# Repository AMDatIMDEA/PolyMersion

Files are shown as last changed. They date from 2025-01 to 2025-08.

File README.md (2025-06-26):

# PolyMersion

Automated Procedure for Polymer Degradation Testing through Water Immersion using UR10-e Robot Arm

---
### Project Structure

This repository contains two versions of the experimental workflow:

- `scripts_v1`: Single-bath experiment version.
- `scripts_v2`: Dual-bath experiment version.

Each version is self-contained and configurable via a `config.json` file and a separate README.md file for a more thorough explanation.

---

## Overview

This repository contains the final version of the CAD models, 3D printable STL files, and Python scripts used to automate and execute the experimental workflow for Polymer Degradation Testing using UR10-e Robot Arm. Also includes the code for the Arduino.

## Repository Structure

```
PolyMersion/ 
├── CAD/ 
├── STL/
├── data/
├── Arduino/
├── scripts_v1/
│ ├── README.md
│ ├── main.py 
│ ├── config.json
│ ├── robot.py
│ ├── gripper.py
│ ├── degradation.py
│ ├── environment.py 
│ └── data_processing.py
├── scripts_v2/
│ ├── README.md
│ ├── client.py
│ ├── listener.py
│ ├── config1.json
│ ├── config2.json
│ ├── robot.py
│ ├── gripper.py
│ ├── degradation.py
│ ├── environment.py 
│ └── data_processing.py
├── requirements.txt
└── README.md
```

## How to use
### 1. 3D Printing Components

- The STL files located in the `STL` folder are ready to be used for 3D printing.
- Print the files according to the material and printer specifications suitable for the experiment.
- Included are files for designing trays for impact and tensile test samples, and a README.md file specifying the tray assembly.

### 2. Wiring the circuit
- Follow the circuit depicted in `Arduino\Schematic.png` using the components listed in the publication describing the experiment or adapting them to your use case.
  
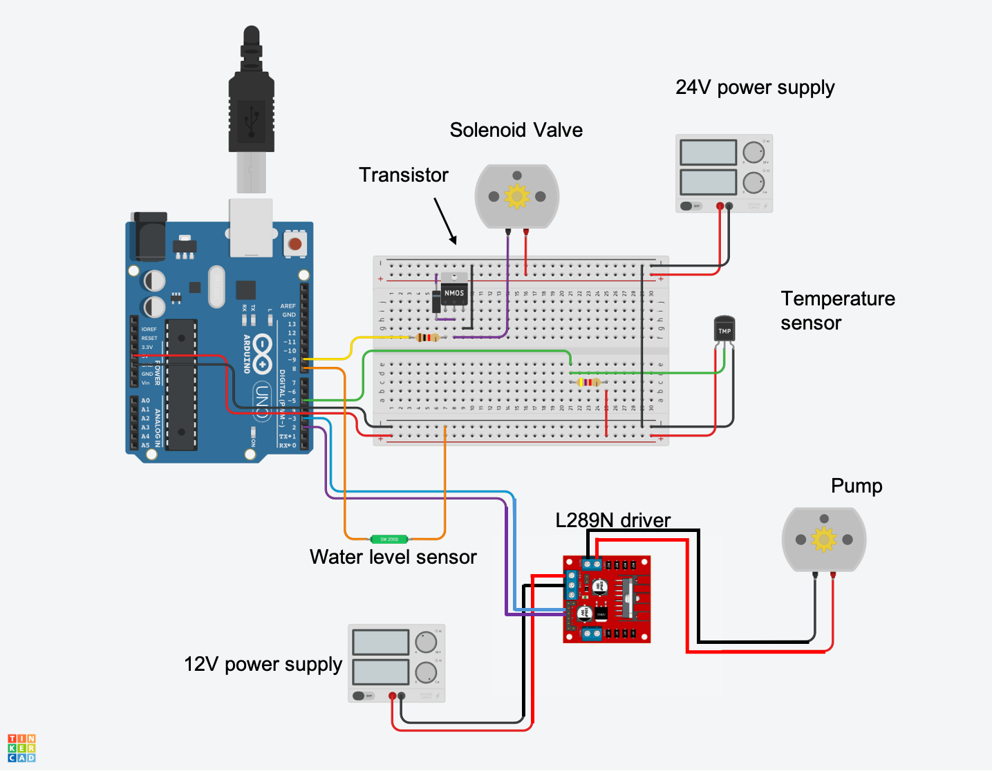
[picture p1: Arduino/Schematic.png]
Circuit schematic


### 3. Running the Workflow

- Parameters such as the number of specimens, cycle length, and other relevant variables can be adjusted by modifying the `config.json` file.
- No changes to the Python code are necessary—simply update the JSON file to reflect the desired settings.

1. Clone this repository:
```
git clone https://github.com/AMDatIMDEA/PolyMersion.git
```

2. Choose the version you want to use:
   - For single bath → `cd PolyMersion/scripts_v1`
   - For dual bath → `cd PolyMersion/scripts_v2`
     
3. Upload the Arduino code:
   ```bash
   cd PolyMersion/Arduino/PoliMersion
   open PoliMersion.ino  # Or use the Arduino IDE
   ```

3. Install the required Python packages:
   ```bash
   pip install -r requirements.txt
   ```

4. Edit the `config.json` file to configure your experiment (see below).

5. Run the workflow following the instructions in the README.md file that you have chosen.

### 4. Configuration

- The `config.json` file allows users to easily configure the experiment without altering the codebase.
- Example of a `config.json` structure:

```
{
    "robot": {
        "robot_ip": "192.168.9.29",
        "setup": 1,
        "choice": 1 # 1: Extract samples to external tray, 2: Leave the samples in the internal tray	
    },
    "experiment": {
        "material": "PLA",
        "temperature": 40,
        "cycles": 23,
        "subcycles": 1,
	"samples_per_subcycle": 10,
	"starting_cycle": 15
    },
    "grid": {
        "columns": 23,
        "rows": 11
    },
    "timing": {
        "hours_delay": 5,
        "minutes_delay": 0
    }
}
```
> 💡 Each version (`scripts_v1`, `scripts_v2`) may have slightly different config parameters depending on bath logic. Check the `config.json` in each folder for version-specific options.

---
## Requirements

- Python 3.x
- Required libraries listed in `requirements.txt`

## Compatibility  

This project has been tested on:

- ✅ macOS
- ✅ Linux
  
> ⚠️ If `python` or `pip` refers to Python 2 on your system, use `python3` and `pip3` instead.

## Notes
- Make sure the 3D printed components match the CAD models used in the experiment.
- If adjustments to the CAD models are required, source files can be found in the CAD folder.

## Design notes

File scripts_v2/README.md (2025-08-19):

# PolyMersion - Two-Bathroom Version (with queuing system)

This version runs the experiment with **two simultaneous baths**, managed through a queuing system. It uses sockets to coordinate the robot's movements in parallel.

---

## Architecture

- `listener.py`: Server that manages queued client requests.
- `client.py`: Client that represents a bath experiment.
- Communication based on TCP/IP sockets.
- Ideal for experiments with multiple groups in parallel.

---

## Execution

1. Navigate to the directory:
```bash
cd PolyMersion/scripts_v2
```

2. Upload the code to Arduino:
```bash
cd ../../Arduino/PoliMersion
open PoliMersion.ino
```

3. Install the dependencies:
```bash
pip install -r requirements.txt
```

4. Run the `listener` (server):
```bash
python listener.py
```

5. In another terminal, run one or more `client.py` scripts:
```bash
python client.py --config config1.json --setup 1
```

---

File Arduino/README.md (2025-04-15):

# Arduino code for PolyMersion experiments

This folder contains the Arduino code to run the Polymersion experiments with one or two water baths. 

The schematics for running with only one bath are presented in the following figure:

Circuit schematic

In case of using two water baths, you will need to install a new water level sensor, temperature sensor and add another pump to the free ports in the L289N driver. 

All Dallas Temperature sensors share the data transfer pin throught the One Wire protocol, and are differenciated by their address. This guide explains in detail the wiring and how to find the adress so it can be scaled to multiple water baths:
https://lastminuteengineers.com/multiple-ds18b20-arduino-tutorial/

To install the Arduino code in the board, use Arduino GUI or the Arduino CLI tool. The OneWire.h and DallasTemperature.h libraries are required.

The code serves three functions:
1. Refill each of the water baths when their corresponding floating switch detects that the water level is low.
2. Send the temperature sensors reading every time it receives a serial request (sent by the python code) to keep track of the temperature.
3. Open the compressed air valve to dry the specimens every time it's requested, again via serial.

The code is commented in detail so every function can be modified if needed to extend functionality or the number of water baths available.

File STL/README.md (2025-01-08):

# 3D Printing Guide for PolyMersion  

## Overview  
This folder contains the STL files required to fabricate the components for the Polymer Degradation Testing setup. The parts are designed to be printed using standard 3D printers and assembled for the UR10-e Robot Arm experiment.  

## Components to Print  

### Required Pieces:  
- **Base Plate (x1)** – The foundational structure for mounting the grid and supporting the specimens.  
- **Top Plate (x1)** – The upper structural part that holds specimens in place.  
- **Intermediate Trays (x2 or more)** – Adjustable trays that hold the polymer samples during testing.
- Remember that 2 trays are neccesary, one for the water bath and the other one outside.  

### Additional Components:  
- **Screw covers** - To maintain the structure.
- **Tray Connectors** – Connectors are included to join trays if they need to be printed in separate sections.  
- **Complements** – Complementary parts as water level controller, scale adapter and gripper. 

## Printing Instructions  
1. **Print Orientation and Size**:  
   - Ensure that large components are printed flat to minimize warping.
     
2. **Printing in Parts**:  
   - The **STL files** in this directory are pre-sliced into three parts for each layer of the tray to fit standard print beds, such as the Bambu printer.
   - CAD files are included to modify this pre-slicing.
   - Use the **tray connectors** to reassemble parts post-printing.  
   - The STL files for the connectors and joining pieces are provided in this folder.  

3. **Material Recommendation**:  
   - Use **ASA** for structural integrity and resistance to degradation under experimental conditions.  
   - Ensure all components are printed with a minimum of 3 perimeters and 30% infill for durability.  

4. **Post-Processing**:  
   - Light sanding may be required to ensure that connectors and assembled sections fit smoothly.  
   - Test-fit all components before final assembly.  

## Assembly Notes  
- Refer to the CAD models to visualize the complete assembly.  
- Ensure the top and base plates align correctly with the trays and connectors.  
- Tighten all clips and connectors to secure the experiment structure.
- If you encounter any issues during printing or assembly, consider scaling components slightly or adjusting slicing parameters. 

## Files Included  
- **STL Files** – Ready-to-print 3D models.  

---
**Note:**  
If adjustments to the design are required, the CAD folder contains the editable models. Modify them as needed to fit your experimental setup or printer specifications.

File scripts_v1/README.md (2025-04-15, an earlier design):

# PolyMersion - Single-Bath Version

This script allows you to automatically run a polymer sample immersion experiment using a single bath, a UR robot, and an Arduino.

---

## Execution

1. Navigate to the directory:
```bash
cd PolyMersion/scripts_v1
```

2. Configure the experiment by editing the `config.json` file.

3. Upload the code to Arduino:
```bash
cd ../../Arduino/PoliMersion
open PoliMersion.ino # Or open it with the Arduino IDE
```

4. Install the dependencies:
```bash
pip install -r requirements.txt
```

5. Run the experiment:
```bash
python main.py
```

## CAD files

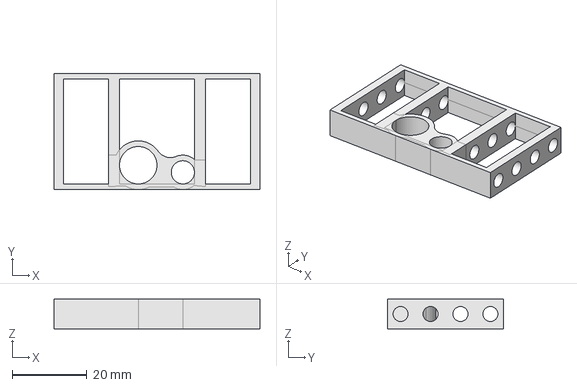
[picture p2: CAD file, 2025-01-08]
CAD/PolyMersion_center_platform.FCStd
55.0 x 31.0 x 8.00 mm

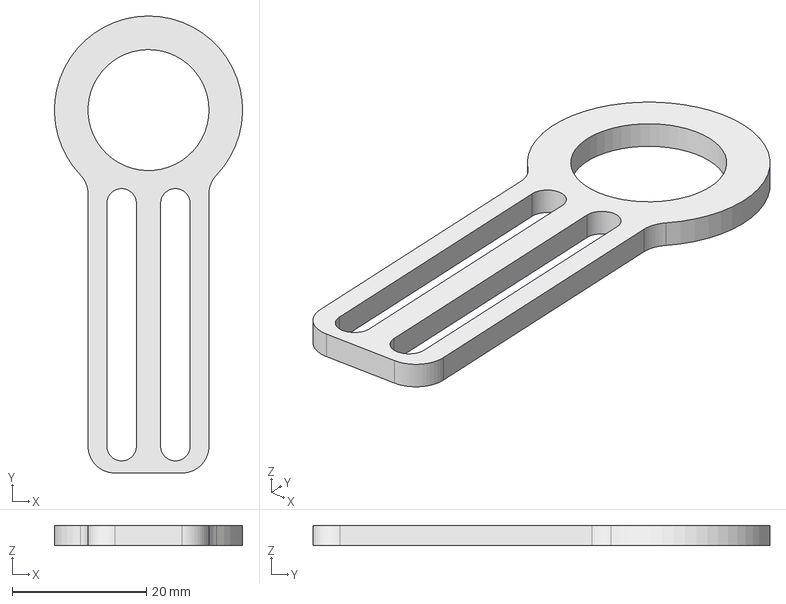
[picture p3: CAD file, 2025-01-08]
CAD/PolyMersion_water_level_control.FCStd
28.0 x 68.0 x 3.00 mm

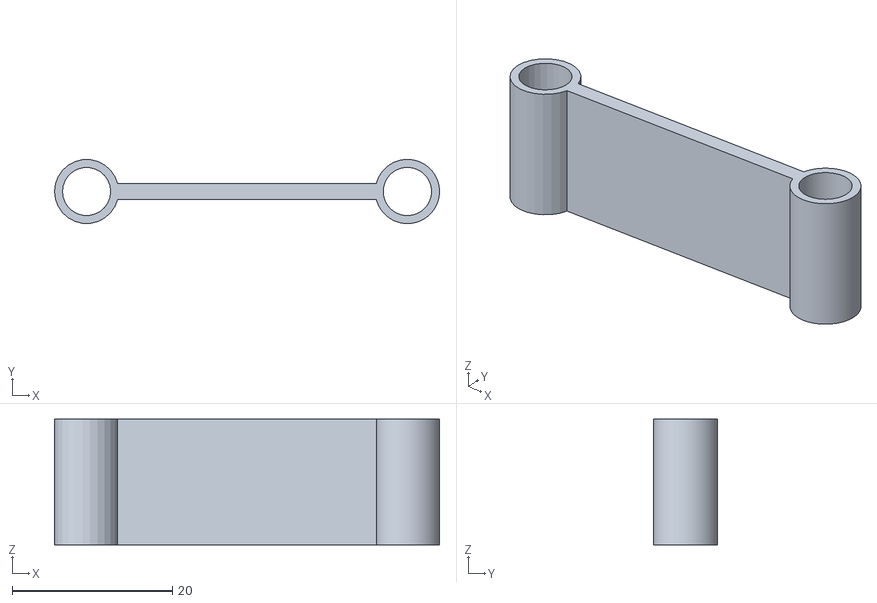
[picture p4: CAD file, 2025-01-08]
STL/PolyMersion_tray_joint.stl
48.0 x 8.00 x 15.7

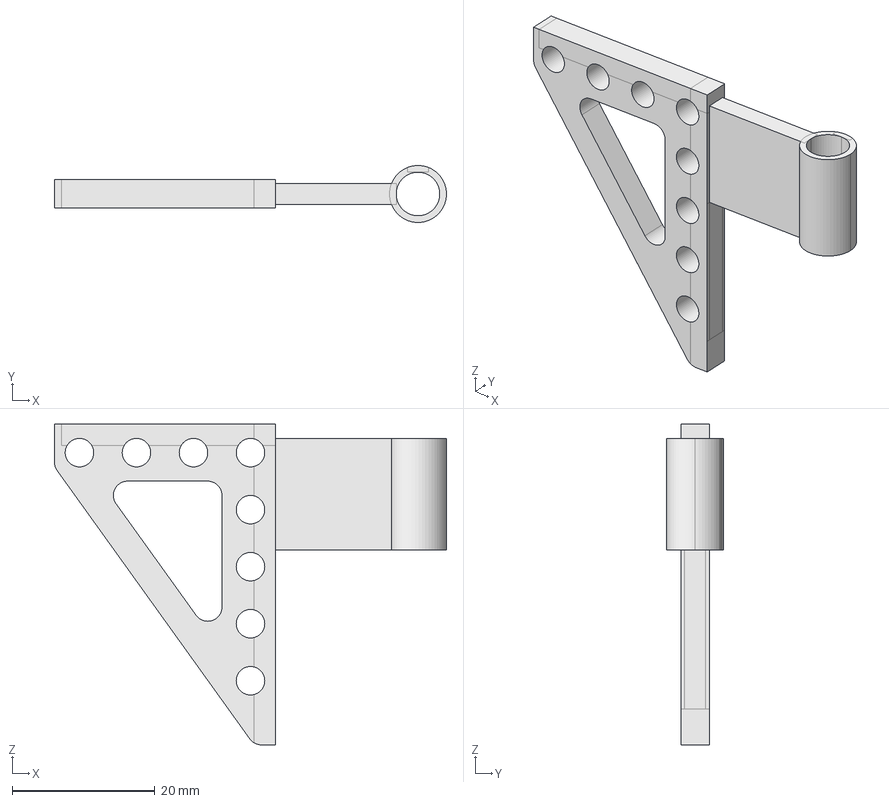
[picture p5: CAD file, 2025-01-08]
CAD/PolyMersion_center_tray_bracket.FCStd
55.0 x 7.99 x 45.0 mm

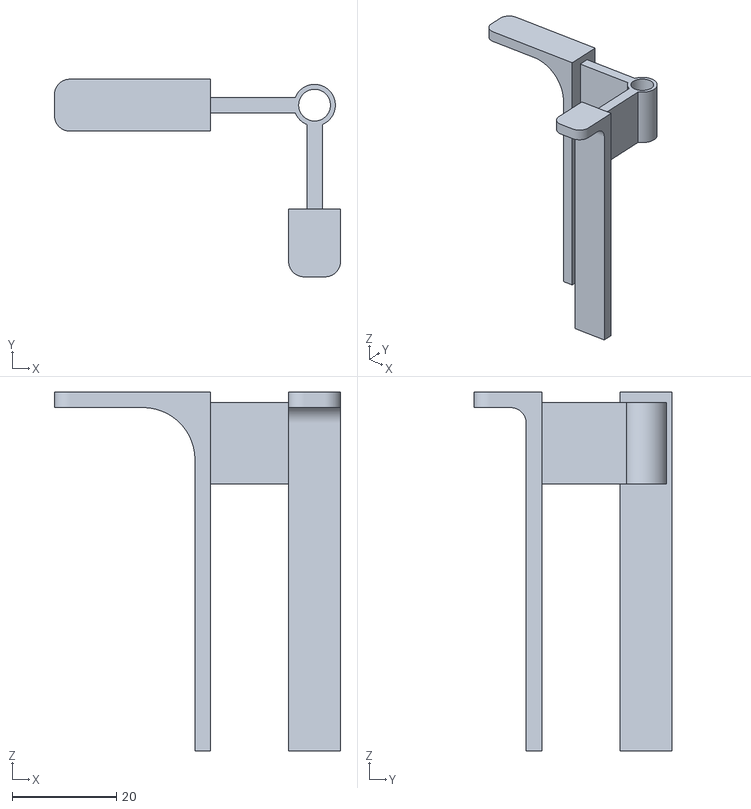
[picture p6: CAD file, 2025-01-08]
STL/PolyMersion_corner_R.stl
55.0 x 38.0 x 69.0

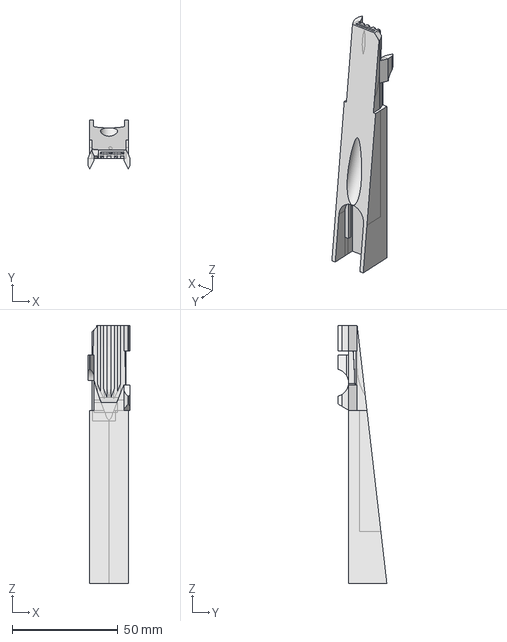
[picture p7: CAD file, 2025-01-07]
CAD/Polymersion_grip_air_8mm.FCStd
20.0 x 23.0 x 121.8 mm

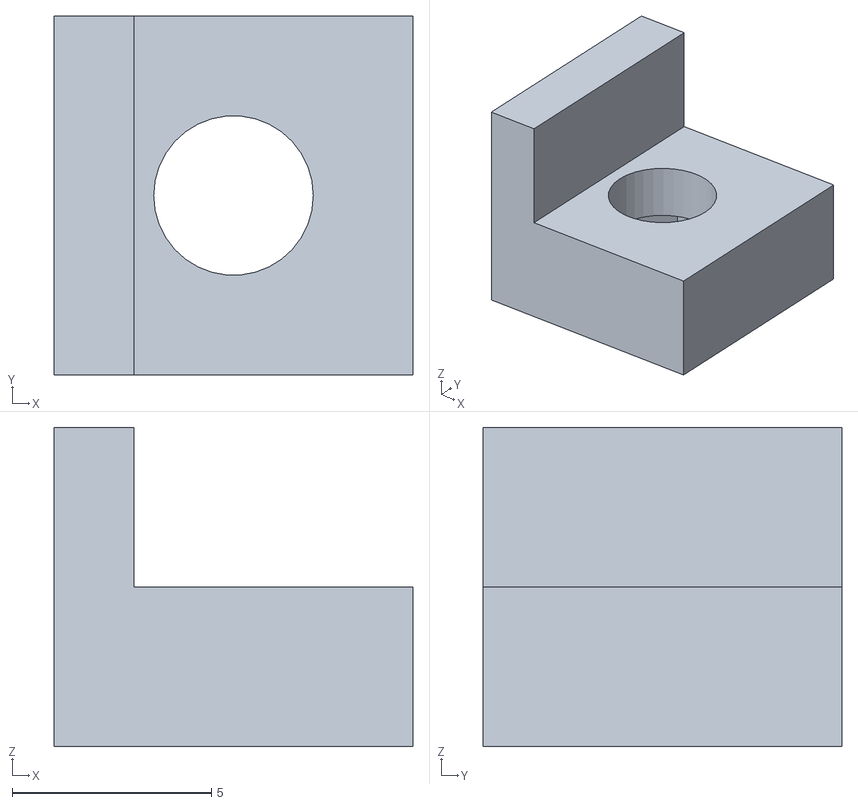
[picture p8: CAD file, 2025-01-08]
STL/PolyMersion_scale_joint.stl
9.00 x 9.00 x 8.00

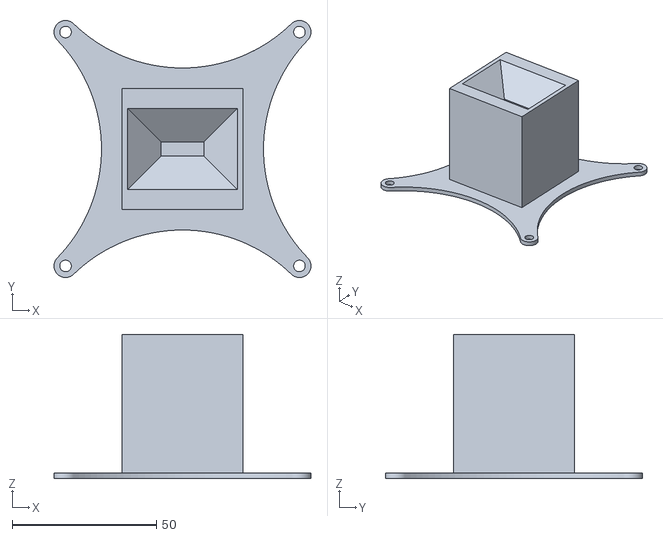
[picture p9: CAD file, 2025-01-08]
STL/PolyMersion_scale_adapter.stl
89.0 x 89.0 x 50.0

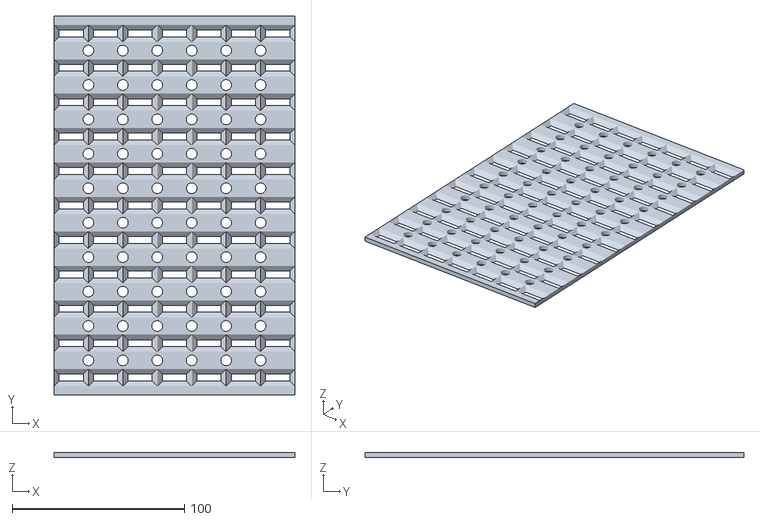
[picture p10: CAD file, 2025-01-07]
STL/PolyMersion_tray_medium_7x11.stl
140.0 x 220.0 x 3.00

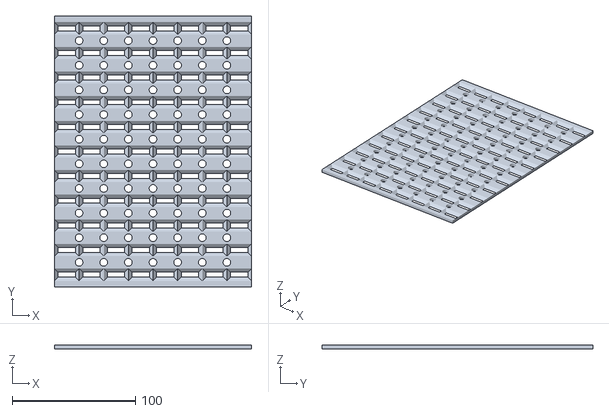
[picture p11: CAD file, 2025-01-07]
STL/PolyMersion_tray_medium_8x11.stl
160.0 x 220.0 x 3.00

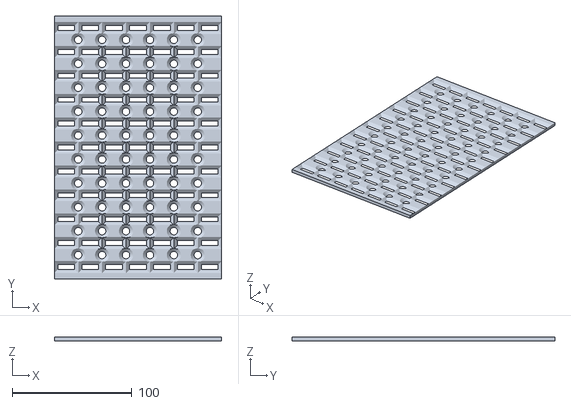
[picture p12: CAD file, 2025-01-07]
STL/PolyMersion_tray_top_7x11.stl
140.0 x 220.0 x 3.00

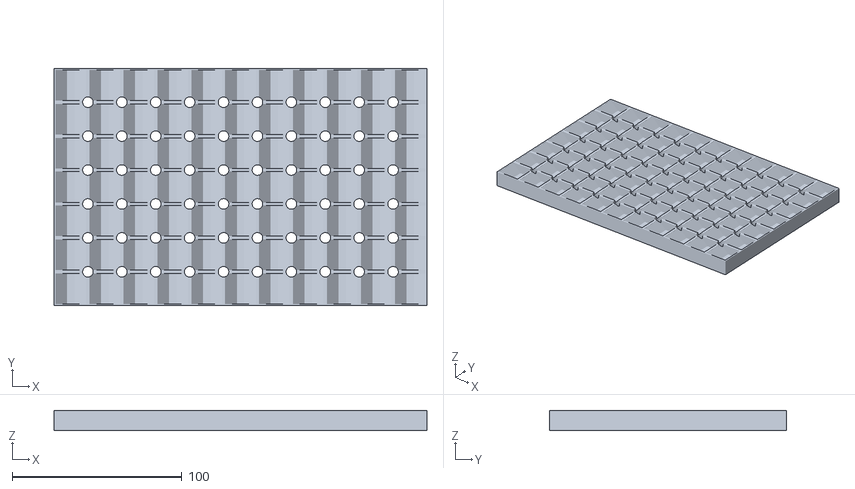
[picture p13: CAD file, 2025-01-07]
STL/PolyMersion_tray_base_7x11.stl
220.0 x 140.0 x 12.0

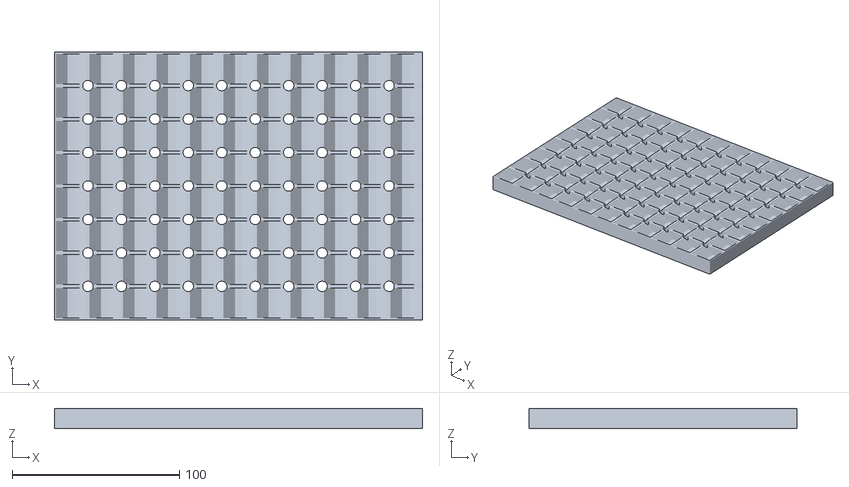
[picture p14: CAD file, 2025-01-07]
STL/PolyMersion_tray_base_8x11.stl
220.0 x 160.0 x 12.0

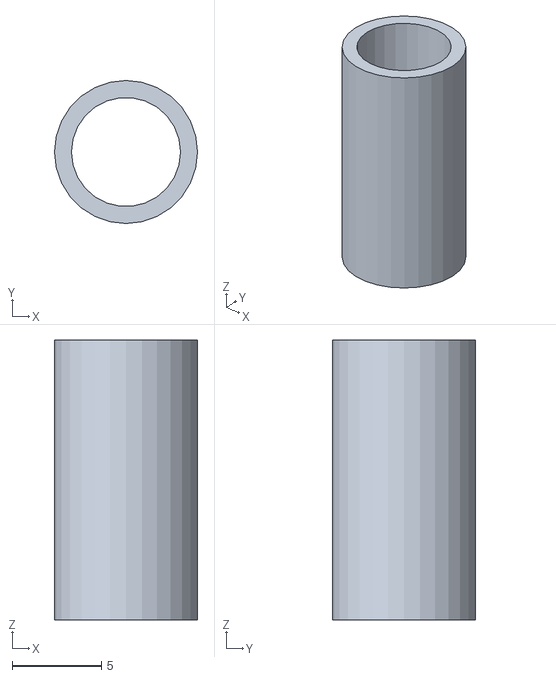
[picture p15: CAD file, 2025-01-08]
STL/PolyMersion_screw_cover.stl
8.00 x 8.00 x 15.7

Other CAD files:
STL/PolyMersion_corner_L.stl
STL/PolyMersion_center_platform.stl
STL/PolyMersion_center_tray_bracket.stl
STL/PolyMersion_grip_air_8mm.stl
STL/PolyMersion_water_level_control.stl

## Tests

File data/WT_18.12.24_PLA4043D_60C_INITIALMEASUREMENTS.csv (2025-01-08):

WT_18.12.24_PLA4043D_60C_INITIAL_MEASUREMENTS
Sample | Measure 1 (g) | Measure 2 (g) | Measure 3 (g) | Average (g) | Time of Test | Temperature (C)
1 |  | 4.308 | 4.311 | 4.312 | 10:26:26 | 2024-12-18 | 19.69
2 | 4.315 | 4.31 | 4.316 | 4.314 | 10:27:46 | 2024-12-18 | 19.69
3 | 4.315 | 4.316 | 4.311 | 4.314 | 10:29:07 | 2024-12-18 | 19.69
4 | 4.322 | 4.32 | 4.318 | 4.32 | 10:30:27 | 2024-12-18 | 19.75
5 | 4.321 | 4.321 | 4.315 | 4.319 | 10:31:47 | 2024-12-18 | 19.69
6 | 4.301 | 4.299 | 4.306 | 4.302 | 10:33:07 | 2024-12-18 | 19.69
7 | 4.316 | 4.31 | 4.314 | 4.313 | 10:34:26 | 2024-12-18 | 19.69
8 | 4.333 | 4.321 | 4.324 | 4.326 | 10:35:46 | 2024-12-18 | 19.69
9 | 4.308 | 4.291 | 4.284 | 4.294 | 10:37:09 | 2024-12-18 | 19.69
10 | 4.307 | 4.308 | 4.304 | 4.306 | 10:38:29 | 2024-12-18 | 19.69
12 | 4.322 | 4.322 | 4.306 | 4.317 | 10:46:49 | 2024-12-18 | 19.75
13 | 4.33 | 4.329 | 4.345 | 4.335 | 10:48:08 | 2024-12-18 | 19.81
14 | 4.329 | 4.322 | 4.325 | 4.325 | 10:49:28 | 2024-12-18 | 19.81
15 | 4.324 | 4.32 | 4.316 | 4.32 | 10:50:50 | 2024-12-18 | 19.81
16 | 4.312 | 4.319 | 4.307 | 4.313 | 10:52:10 | 2024-12-18 | 19.81
17 | 4.316 | 4.321 | 4.317 | 4.318 | 10:53:30 | 2024-12-18 | 19.87
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

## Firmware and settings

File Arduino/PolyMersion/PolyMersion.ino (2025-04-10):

// Import libraries for temperature sensor communication

#include <OneWire.h>
#include <DallasTemperature.h>

/* 
  ===== Pin Definitions =====
  These constants define the pins connected to the pumps, water level switches, 
  temperature sensor bus, and the air valve.
*/


const int pump_1 = 3;      // Pump 1 control pin for filling direction
const int pump_2 = 2;      // Pump 1 control pin for oposite direction, always kept at LOW
const int pump_3 = 10;     // Pump 2 control pin for filling direction
const int pump_4 = 11;     // Pump 2 control pin for oposite direction, always kept at LOW

const int waterLevel = 8;  // Digital input for water level sensor 1
const int waterLevelB = 7; // Digital input for water level sensor 2

const int oneWirePin = 5;  // Digital pin used for OneWire temperature sensor communication

const int valvePin = 9;    // Digital output for the air valve control


// State tracking booleans to avoid repetitive pump start messages.
bool pumpingStarted = false;
bool pumpingStartedB = false;

/* 
  ===== Temperature Sensor Address Setup =====
  These DeviceAddress arrays store the unique addresses for two temperature sensors.
*/
DeviceAddress sensor = {0x28, 0xFF, 0x64, 0x1E, 0x01, 0xD9, 0xA5, 0xBA};   // Sensor 1 address
DeviceAddress sensorB = {0x28, 0xAE, 0x17, 0x46, 0xD4, 0x25, 0x56, 0x2A};  // Sensor 2 address


// Create OneWire bus object and DallasTemperature object for sensor communications.
OneWire oneWireBus(oneWirePin);
DallasTemperature sensors(&oneWireBus);

/*
  ===== Setup Function =====
  This function runs once at startup to configure pin modes and initialize sensors.
*/

void setup() {
  // Start Serial communication for debug and command input.
  Serial.begin(9600);
  
  // Initialize the temperature sensors.
  sensors.begin();
  
  // Set pump control pins as outputs.
  pinMode(pump_1, OUTPUT);
  pinMode(pump_2, OUTPUT);
  pinMode(pump_3, OUTPUT);
  pinMode(pump_4, OUTPUT);
  
  // Set water level sensor pins as inputs.
  pinMode(waterLevel, INPUT);
  pinMode(waterLevelB, INPUT);
  
  // Set the valve control pin as output.
  pinMode(valvePin, OUTPUT); 

  // Initialize pump outputs to stop pumps (0 speed).
  analogWrite(pump_1, 0);
  analogWrite(pump_2, 0);
  analogWrite(pump_3, 0);
  analogWrite(pump_4, 0);
  
  // Activate internal pull-ups for water level sensors.
  // This ensures a default HIGH state when the sensors are inactive.
  digitalWrite(waterLevel, HIGH);
  digitalWrite(waterLevelB, HIGH);
}

/*
  ===== Main Loop Function =====
  The loop() checks water levels, controls pumps accordingly, and also reads serial commands.
*/
void loop() {
  // Read the state of water level sensors (HIGH means water is below the threshold)
  int sensorState = digitalRead(waterLevel); 
  int sensorStateB = digitalRead(waterLevelB);
  
  // Wait for 1 second between readings
  delay(1000); 

  // Buffer to store an incoming serial command (up to 10 characters).
  char cmd[10];                        
                    
  /* 
    ----- Water Level Bath 1 Control -----
    When sensorState is HIGH, it means the water level is below the switch threshold.
    Thus, pump_1 is activated with a set speed (80), that can be adjusted if using a different pump.
    A flag 'pumpingStarted' is used to track pump status.
  */  
  if (sensorState == HIGH) { 
      analogWrite(pump_1, 80);  
      analogWrite(pump_2, 0);
      if (!pumpingStarted) {  
          pumpingStarted = true;
    }
  }
  else {
    // If the water level is sufficient, stop the pump.
    analogWrite(pump_1, 0);
    analogWrite(pump_2, 0);
    pumpingStarted = false;
   }
  /* 
    ----- Water Level Bath 2 Control -----
    When sensorStateB is HIGH, it means the water level is below the switch threshold.
    Thus, pump_2 is activated with a set speed (80), that can be adjusted if using a different pump.
    A flag 'pumpingStartedB' is used to track pump status.
  */  
  if (sensorStateB == HIGH) { 
      analogWrite(pump_3, 80);  
      analogWrite(pump_4, 0);
      if (!pumpingStartedB) {  
          pumpingStartedB = true;
    }
  }
  else {
    // If the water level is sufficient, stop the pump.
    analogWrite(pump_3, 0);
    analogWrite(pump_4, 0);
    pumpingStartedB = false;
   }
 
/* 
    ----- Serial Command Processing -----
    The following code checks if a command was sent via Serial and processes it.
    Supported commands:
      - "PUMP": Activate pump 1.
      - "STOP": Stop pump 1.
      - "TEMP": Read and print temperature from sensor 1.
      - "TEMPB": Read and print temperature from sensor 2.
      - "OPEN VALVE": Open the air valve.
      - "CLOSE VALVE": Close the air valve.
  */
 if (readSerial(cmd)) {
    // Convert the received command to uppercase to make comparisons case-insensitive.
    toUpperCase(cmd);
    if (strstr(cmd, "PUMP")) {                                                       //PUMP ONLY
      analogWrite(pump_1, 80);   //255=full speed, 0=stop, 127=half speed
      analogWrite(pump_2, 0);
    }  
    else if (strstr(cmd, "STOP")) {                                                  //STOP PUMP
      analogWrite(pump_1, 0);
      analogWrite(pump_2, 0);
      //Serial.println("Stop");
    }
    else if (strstr(cmd, "TEMP")) {                                                  //READ TEMPERATURE
      printTemperature();
    }
    else if (strstr(cmd, "TEMPB")) {                                                  //READ TEMPERATURE B
      printTemperatureB();
    }
    else if (strstr(cmd, "OPEN VALVE")) {                                            //OPEN VALVE
      digitalWrite(valvePin, HIGH);
    }
    else if (strstr(cmd, "CLOSE VALVE")) {                                           //CLOSE VALVE
      digitalWrite(valvePin, LOW);
    }
  } 

}
/*
  ===== Helper Function: readSerial =====
  Reads characters from Serial until a newline is encountered, then terminates the string.
  Returns true if a complete command was read, false otherwise.
*/
int i = 0; // Global index for storing incoming characters
bool readSerial(char result[]) {
  while (Serial.available() > 0) {       // Check if there is any data in the Serial buffer
    char inChar = Serial.read();         // Read one character from the Serial buffer
    
    if (inChar == '\n') {                // Check if the character is the newline character
      result[i] = '\0';                  // Terminate the string with a null character
      Serial.flush();                    // Clear the serial transmit buffer (and in older versions,
                                         // it was sometimes used to clear the input - see note below)
      i = 0;                             // Reset index for the next command
      return true;                       // Indicate that a complete command has been read
    }
    // Ignore carriage return characters so they don't clutter the result
    if (inChar != '\r') {
      result[i] = inChar;                // Store the character in the result array
      i++;                               // Increment the index for the next incoming character
    }
    delay(1);                            // Small delay to allow other Serial events
  }
  return false;                          // No complete command was received yet
}

/*
  ===== Helper Function: toUpperCase =====
  Converts a given C-string to uppercase in place.
*/
void toUpperCase(char* str) {
  if (str == NULL) return;
  for (int i = 0; str[i] != '\0'; i++) {
    str[i] = toupper(str[i]);
  }
}

/*
  ===== Helper Function: printTemperature =====
  Requests temperature readings from sensor 1 and prints the temperature in Celsius to Serial.
*/
void printTemperature() {
  sensors.requestTemperatures();
  Serial.print("Temperature at sensor 1: ");
  Serial.print(sensors.getTempC(sensor));
  Serial.println(" ºC");
}
/*
  ===== Helper Function: printTemperatureB =====
  Requests temperature readings from sensor 2 and prints the temperature in Celsius to Serial.
*/
void printTemperatureB() {
  sensors.requestTemperatures();
  Serial.print("Temperature at sensor 2: ");
  Serial.print(sensors.getTempC(sensorB));
  Serial.println(" ºC");
}

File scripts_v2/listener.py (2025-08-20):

import socket
import threading
import queue, time
import json

import time
import os
import numpy as np
import math
import copy
import csv
import json
import pandas as pd
import matplotlib.pyplot as plt

import robot
import gripper
import environment
import data_processing
import degradation

# Queue to hold incoming commands
command_queue = queue.Queue()

# Flag to indicate if the robot is busy
is_busy = False

PORT = 5000

# CODE FOR EXPERIMENT IN THIS FUNCTION

def execute_command(command_data):
    """
    Execute a robot command using the ur-rtde API.
    """
    global is_busy
    is_busy = True
    
    print("Experiment running") 
    
    setup = command_data.get("setup")
    print("Performing experiment using setup ", setup)

    with open("config.json", "r") as file:
        config = json.load(file)
    
    robot_ip = config["robot"]["robot_ip"]
    setup = command_data.get("setup")
    material = command_data.get("material")
    temperature = command_data.get("temperature")
    date = command_data.get("date")
    rows = command_data.get("rows")
    columns = command_data.get("columns")
    choice = command_data.get("choice")
    name = f"{material}_{temperature}_{date}"

    print("\n--- Robot Connection ---")
    print("Connecting to the robot...")
    rtde_c, rtde_r, rtde_io = robot.connect_robot(robot_ip)
    print("Robot connected successfully.")
    robot.set_initial_position(rtde_c, setup)

    photo_dir = f"../data/Photos_{name}"
    if not os.path.exists(photo_dir): # Check if directory exists
        os.makedirs(photo_dir)
        print(f"Directory '{photo_dir}' created.")
    else:
        print(f"Directory '{photo_dir}' already exists.")
    
    temperature_registry = f"../data/TemperatureRegistry_{name}.txt"
    prev_time = int(time.strftime('%H%M%S', time.localtime()))

    # Robot Environment settings
    SAMPLE = environment.generate_sample_grid(columns,rows)

    OFFSET = -.068  # Z offset
    gripper_length = .05  # Gripper length adjustment
    OFFSET += gripper_length
    
    scale_access_remote = input("Allow remote scale access? (y/n): ").lower() == "y"
    remote, balance = environment.setup_remote_scale(scale_access_remote)

    # Obtener la posición actual del robot
    lid_position = rtde_r.getActualTCPPose()  # Devuelve [X, Y, Z, RX, RY, RZ]
    print(f"Posición actual: {lid_position}")

    # Posición base del primer setup
    if setup == 1:
        lid_deposition = [-0.24133534388522648, 0.2131944897595923, 0.35, 2.224008047304794, -2.2121364315342986, -0.010991599941659188]
    elif setup == 2:
        lid_deposition = [0.6556738335891733, -0.32250568064465923, 0.4362477404307668, 2.267314033738123, -2.13353507951682, 0.026926286486254704]

    cycle_number = config["experiment"]["starting_cycle"]
    fields = ['Sample', 'Measure 1 (g)', 'Measure 2 (g)', 'Measure 3 (g)', 'Average (g)', 'Time of Test', 'Temperature (C)']  # Fields for the CSV

    print("_Removing lid...")
    rtde_c.moveL(lid_position, 3, 1)
    temporal_position = rtde_r.getActualTCPPose()
    degradation.move_lid('off', rtde_c, rtde_r, rtde_io)
    temporal_position[2] = .3 + OFFSET
    print("_Callibrating...")
    intersection, angle_deviation = degradation.center(temporal_position, rtde_c, rtde_r, rtde_io, OFFSET)
    X_intersection = intersection[0]
    Y_intersection = intersection[1]
        
    # Preparation
    gripper.open_grip(15, rtde_c, rtde_r, rtde_io)
    rtde_c.moveL(intersection, 3, 1)

    # Calculate positions for sponge and scale
    sponge_position = rtde_r.getActualTCPPose()
    X_sponge = .225
    Y_sponge = -.125 + .02
    sponge_position[0] = X_intersection + (X_sponge * math.cos(angle_deviation) - Y_sponge * math.sin(angle_deviation))
    sponge_position[1] = Y_intersection + (Y_sponge * math.cos(angle_deviation) + X_sponge * math.sin(angle_deviation))

    if setup == 2:
        scale_position = [0.10645207840498347, 0.6936982017571437, 0.28658622705355286, -2.222037213084921, 2.2142596251486433, -0.007182138314705186]

    elif setup == 1:
        scale_position = rtde_r.getActualTCPPose()

        X_scale = 0.1365 + 0.165
        Y_scale = -0.1875

        scale_position[0] = X_intersection + (
            X_scale * math.cos(angle_deviation) - Y_scale * math.sin(angle_deviation)
        )
        scale_position[1] = Y_intersection + (
            Y_scale * math.cos(angle_deviation) + X_scale * math.sin(angle_deviation)
        )
        scale_position[2] -= 0.095
        
    # Move and rotate the gripper
    J0 = rtde_r.getActualQ()
    J0[-1] -= angle_deviation
    rtde_c.moveJ(J0, 3, 1)
    P0 = rtde_r.getActualTCPPose()
    P0[2] -= .16
    rtde_c.moveL(P0, 3, 1)

    filename = f"../data/WT_{time.strftime('%d.%m.%y', time.localtime())}_{name}"
    csv_file = filename + '.csv'
    png_file = filename + '.png'
    time.sleep(1)
    
   
    for sample in command_data.get("samples"):
        print("__Measuring sample " + str(sample))
        n =int(sample)
        time.sleep(1)

        # CALCULATE GRID POSITION 
        P0 = rtde_r.getActualTCPPose()
        # Pull coords from class
        xtemp = .02 * (SAMPLE[n].index[0] - 1)
        ytemp = .02 * (SAMPLE[n].index[1] - 1)
        P0[0] = X_intersection + (xtemp * math.cos(angle_deviation) - ytemp * math.sin(angle_deviation))  # Rot transformation X
        if n > 121:
            P0[0] += 0.003
        P0[1] = Y_intersection + (ytemp * math.cos(angle_deviation) + xtemp * math.sin(angle_deviation))  # Rot transformation Y
        rtde_c.moveL(P0, 0.3, 1)

        # CALCULATE DEPOSIT POSITION
        PD = copy.copy(lid_deposition)

        PD[0] += xtemp
        PD[1] += ytemp

        # Sample collection (Picking the sample)
        P0 = rtde_r.getActualTCPPose()
        initial_position = copy.copy(P0)

        # Move down to collect sample
        P0[2] -= .04  # .05 or .21 depending on the position
        rtde_c.moveL(P0, .05)
            
        # Open grip slightly to help center the sample
        gripper.open_grip(15, rtde_c, rtde_r, rtde_io)  # Opening the gripper slightly
            
        # Shake sample to ensure it's secured
        degradation.shake(rtde_c, rtde_r, rtde_io)
        gripper.open_grip(10, rtde_c, rtde_r, rtde_io)  # Slightly opening to release tension
            
        # Shake it again to make sure it's secure
        degradation.shake(rtde_c, rtde_r, rtde_io)
            
        # Close the grip to secure the sample
        gripper.close_grip(rtde_c, rtde_r, rtde_io, force=25)
            
        # Move the gripper up to the collection position
        P0[2] += .2  # .21 or appropriate distance for sample collection
        rtde_c.moveL(P0, 3, 1)
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
